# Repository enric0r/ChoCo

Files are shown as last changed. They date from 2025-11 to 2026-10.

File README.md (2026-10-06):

# ChoCo

**A USB MIDI chord controller built around a Raspberry Pi Pico.**

Choose a scale, hold a degree key, and move the joystick to change the chord. ChoCo sends MIDI notes to a software instrument, DAW, or compatible MIDI host; the connected instrument produces the sound. The OLED shows the current chord and playing modes.

[Website](https://enric0r.github.io/choco.github.io/) · [English handbook](https://enric0r.github.io/choco.github.io/docs/) · [Guida in italiano](https://enric0r.github.io/choco.github.io/it/docs/) · [Releases](https://github.com/enric0r/ChoCo/releases)

<p align="center">
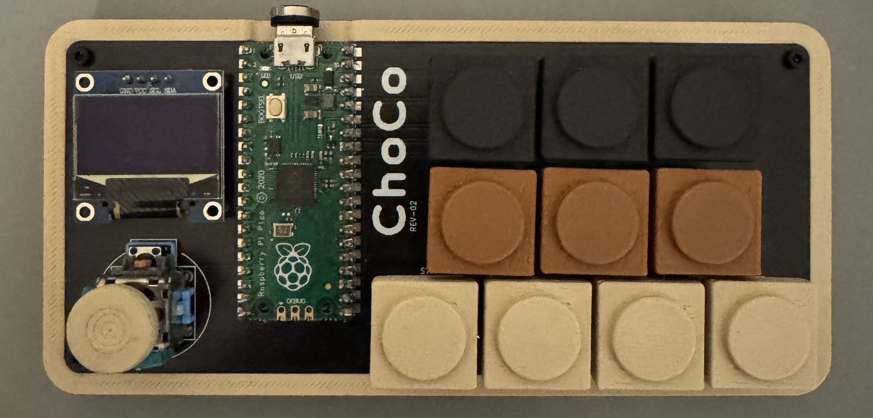
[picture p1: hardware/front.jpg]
Assembled ChoCo prototype: OLED, Raspberry Pi Pico, joystick and ten keys
  
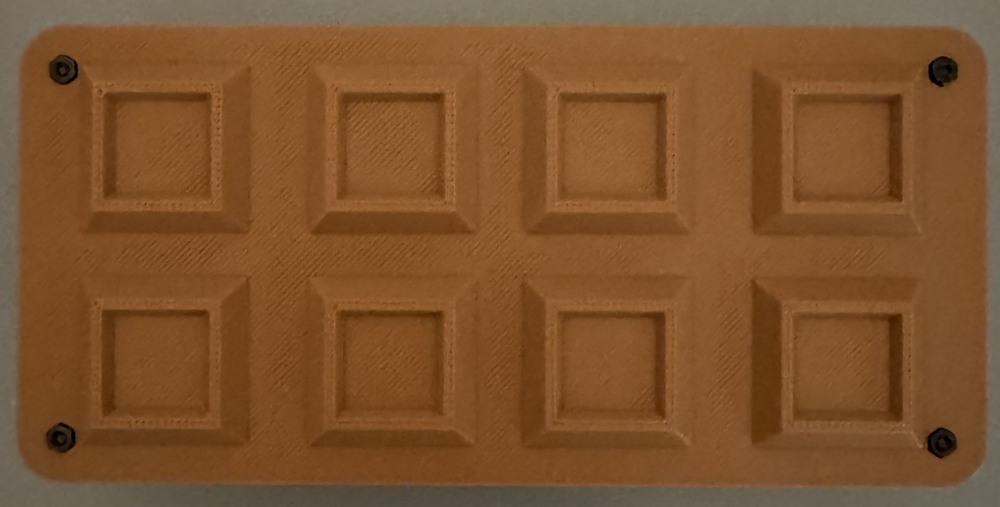
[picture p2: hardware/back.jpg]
Back of the ChoCo prototype, shaped like a chocolate bar
  
</p>

## What you can play

- **Chords in a scale.** Seven degree keys select diatonic chords. Change the root note and choose from nine scales.
- **Chord variations.** Move the joystick for suspensions, sevenths, extensions and other variations. Return it to the center for the base triad.
- **Different ways to play.** Use latch to sustain a chord, add a bass note, stagger notes with strum, or switch to single notes.
- **Inversions and voicing.** Store an inversion for each degree or enable smart voicing.
- **Feedback on the device.** The 128×64 OLED shows key, scale, chord, mode badges and harmonic suggestions.

ChoCo sends class-compliant USB MIDI through TinyUSB. This repository contains the firmware, KiCad hardware files and [STL files for the case](hardware/case/).

## Play your first chord

For an assembled controller:

1. Install the firmware if needed. Download a UF2 from [Releases](https://github.com/enric0r/ChoCo/releases), when available, or [build it below](#build-and-flash).
2. Connect ChoCo with a USB **data** cable.
3. Select its USB MIDI input in your DAW or MIDI host and load an instrument.
4. Hold key `0` to play the first degree of the selected scale.
5. Move the joystick while holding the key, then return it to the center to hear the base chord again.

Start with the [English setup guide](https://enric0r.github.io/choco.github.io/docs/#get-started) or [guida italiana](https://enric0r.github.io/choco.github.io/it/docs/#get-started) for the full walkthrough.

## Controls at a glance

The two upper rows sit halfway between the four white keys. Labels below follow the firmware:

```text
  A   B   C
  1   3   5
0   2   4   6
```

| Control | Action |
| --- | --- |
| `0–6` | Play one of the seven scale degrees |
| `A` | Raise the root by one semitone |
| `B` | Select the next scale |
| `C` | Hold as a modifier for shortcuts |
| Joystick tilt, with a degree held | Change the chord variation |
| `C` + `0–6` | Cycle the inversion for that degree |
| `C` + `A` | Toggle chord latch when A is released; cancelled if the joystick button is used for strum |
| Joystick short press, without `C` | Stop the chord and cancel pending strum notes, keeping the selected modes |
| Joystick long press, without `C` | Toggle single-note mode |

The [illustrated control map](https://enric0r.github.io/choco.github.io/docs/#controls) covers bass, strum, octave changes and the other shortcuts. See [chord variations](https://enric0r.github.io/choco.github.io/docs/#shape-a-chord) for the three joystick maps and [modes and display](https://enric0r.github.io/choco.github.io/docs/#modes-and-display) for the OLED guide.

## Build and flash

Install PlatformIO, then open this repository in a terminal or in VS Code with the PlatformIO extension. The firmware uses the Arduino RP2040 core and the `pico` environment.

```powershell
pio run
```

The UF2 file is written to `.pio/build/pico/firmware.uf2`. To install it:

1. Disconnect the Pico.
2. Hold **BOOTSEL** while connecting it over USB.
3. Copy the UF2 to the **RPI-RP2** drive. The board restarts automatically.

You can also upload through PlatformIO:

```powershell
pio run -t upload
```

`platformio.ini` sets `upload_port = COM5` for local development. Override it locally if your board uses another port. Keep the TinyUSB and network-disable build flags: they are required for this USB MIDI setup.

Serial logging is disabled by default. For diagnostics, set `CHOCO_LOG_LEVEL` in [Config.h](lib/Config/Config.h), rebuild, and run `pio device monitor`. See [DEBUGGING.md](DEBUGGING.md) for the diagnostic steps.

## Hardware and configuration

The prototype uses a Raspberry Pi Pico, ten keys wired as a 3×4 matrix, an analog joystick with a push switch, and an SSD1306-compatible 128×64 I²C OLED.

| Connection | Default pins |
| --- | --- |
| Keypad rows | GP2, GP1, GP0 |
| Keypad columns | GP3, GP4, GP5, GP6 |
| Joystick X / Y | A0 / A1 |
| Joystick switch | GP13 |
| OLED SDA / SCL | GP14 / GP15, on `Wire1` |

The [hardware directory](hardware/) contains the [schematic](hardware/ChoCo.kicad_sch), [PCB layout](hardware/ChoCo.kicad_pcb), [KiCad project](hardware/ChoCo.kicad_pro) and [REV-02 archive](hardware/ChoCo_REV-02.zip).

### 3D-printed case

The [case files and printing notes](hardware/case/) include three separate STL models exported from the Fusion 360 design:

- [Top frame](hardware/case/ChoCo-top.stl)
- [Chocolate-bar bottom](hardware/case/ChoCo-bar-bottom.stl)
- [Joystick cap](hardware/case/ChoCo-thumbstick.stl)

Import the files in millimeters at 100% scale. Each file contains one part; no slicer profile is included yet.

### Prototype bill of materials

For one ChoCo, the project files describe the parts below. This is a record of
the prototype design; exact purchased models and suppliers are still being
confirmed. See the [detailed BOM and assembly notes](hardware/BOM.md).

| Qty | Part | Project detail |
| --- | --- | --- |
| 1 | ChoCo PCB | Prototype marked REV-02 |
| 1 | Raspberry Pi Pico | RP2040 module, `A1` |
| 1 | 128×64 I²C OLED | SSD1306-compatible firmware; `J1` |
| 1 | Two-axis analog joystick with push switch | PS4-style footprint; exact model to confirm |
| 10 | Mechanical key switches | MX-style 1u PCB footprints; `S1–S10` |
| 10 | Matrix diodes | Axial DO-35 footprints; `D1–D10`; symbol describes the 1N4148 family |
| 10 | Keycaps | Visible in the prototype; exact model to confirm |
| 1 | Enclosure / base assembly | Visible in the prototype; fabrication details to confirm |
| 1 | USB data cable | Match the connector on the installed Pico |

Headers, sockets and mounting hardware depend on the actual assembly; they are
listed separately in the detailed BOM so they are not mistaken for additional
schematic components.

Pin assignments, joystick orientation and thresholds, display timings, logging and mode defaults live in [lib/Config/Config.h](lib/Config/Config.h). The [hardware guide](https://enric0r.github.io/choco.github.io/docs/#hardware) and [configuration reference](https://enric0r.github.io/choco.github.io/docs/#configuration) explain these settings.

## Developing the firmware

| Path | Purpose |
| --- | --- |
| [src/main.cpp](src/main.cpp) | Setup and main loop |
| [lib/Controls](lib/Controls/) | Keypad and joystick input |
| [lib/ChordEngine](lib/ChordEngine/) | Chords, inversions, voicing and history |
| [lib/Display](lib/Display/) | OLED rendering and status |
| [lib/MIDI](lib/MIDI/) | USB MIDI transport |
| [lib/Config](lib/Config/) | Shared configuration |
| [test/logic](test/logic/) | Host-side logic tests |

Read [CONTRIBUTING.md](CONTRIBUTING.md) before changing the firmware. Keep the main loop responsive and put hardware settings in `Config.h`.

<details>
<summary>OLED and input implementation notes</summary>

### OLED layout

The header shows the selected key/scale and active degree (`D1..D7`), or `EDIT`
while C is held. The chord is centered at the largest size that fits. The arrow
tracks joystick direction with the horizontal mirror removed; the existing
vertical mapping is preserved for the mounted device.

Active modes appear as a compact text line: `VOI` (smart voicing), `BAS` (bass),
`NOTE` (single note), `STR` (strum), `LAT` (latch). The footer normally shows
`NEXT` suggestions. Temporary confirmations replace only the footer so the
chord stays readable. Long text is fitted or explicitly truncated.

Startup uses a static CHOCO wordmark. The screensaver moves the same wordmark
with the selected key/scale on a separate line; it does not blink or invert.

### Responsiveness and feedback

- Each key and the joystick button use a 10 ms stable-edge debounce, including releases. A newly pressed degree takes over from a held degree; releasing it stops playback unless latch is enabled. Previously held degrees do not retrigger automatically. Exactly simultaneous presses select the lowest degree.
- Strum note-ons are scheduled without blocking input, and pending notes are cancelled on release or chord replacement. Smart voicing preserves only notes that have actually started.
- OLED updates remain limited to 100 ms, skip unchanged frames, and wait for pending strum notes. The first key press wakes the screen and performs its action. Sounding chords keep the screen awake.
- Joystick feedback and new chord attacks share the same hysteresis state, so a variation remains selected until the stick crosses the release threshold. Degree release is processed before joystick changes to prevent a brief extra chord on release.
- Chord names use the lowest note of the resulting voicing for slash notation, including the optional bass pedal. Bass toggles apply immediately; other voicing settings apply when the next chord is generated. The top bar shows the selected key/scale, while the main name describes the active chord.
- Display degrees `1..7` correspond to physical keys `0..6`. `NEXT` contains harmonic suggestions, not a prediction or a correctness score.
- Chord names, history and status messages use fixed buffers. Release builds keep serial output disabled; `C+B` reports this on screen unless INFO logging is enabled.

These are software guarantees covered where possible by host tests. End-to-end latency, matrix ghosting with multiple keys, OLED appearance and USB behaviour still require testing on the physical board and MIDI host.

</details>

### Testing

CI runs six host test programs and builds the firmware with `pio run`. Host tests need a native C++17 compiler; `pio test` is not configured.

<details>
<summary>Run the host logic tests with PowerShell</summary>

```powershell
New-Item -ItemType Directory -Force .test | Out-Null

g++ -std=c++17 -Wall -Wextra -pedantic -Ilib/ChordEngine test/logic/test_chord_logic.cpp -o .test/choco_logic_tests.exe
.test/choco_logic_tests.exe

g++ -std=c++17 -Wall -Wextra -pedantic -Ilib/Controls test/logic/test_joystick_direction.cpp -o .test/choco_joystick_tests.exe
.test/choco_joystick_tests.exe
```

</details>

USB delivery, joystick behavior and the OLED also need checks on a real controller and MIDI host. Follow the hardware checks in [DEBUGGING.md](DEBUGGING.md).

Run the complete suite on Linux, macOS or WSL with a native C++ compiler:

```bash
bash test/run_host_tests.sh
```

On Windows with Ubuntu installed in WSL: `wsl -d Ubuntu -- bash test/run_host_tests.sh`.
The suite covers degree bounds, scale wrapping, inversions, joystick classification, contact bounce, timer rollover, cancellable strum, overlapping keys, latch/strum shortcuts, bass ownership and chord labels. The integration test runs the actual main loop, controls and chord engine with simulated GPIO, time and MIDI. It does not emulate USB or OLED hardware. A cross-compiler such as `arm-none-eabi-g++` cannot run these host tests.

## Help and documentation

For missing MIDI input, a blank OLED or unexpected controls, start with the [troubleshooting guide](https://enric0r.github.io/choco.github.io/docs/#troubleshooting). For a reproducible problem, [open an issue](https://github.com/enric0r/ChoCo/issues).

The handbook is available in [English](https://enric0r.github.io/choco.github.io/docs/) and [Italian](https://enric0r.github.io/choco.github.io/it/docs/), with control diagrams and OLED examples. Its source lives in [choco.github.io](https://github.com/enric0r/choco.github.io).

## License

ChoCo is distributed under the [PolyForm Noncommercial License 1.0.0](LICENSE).

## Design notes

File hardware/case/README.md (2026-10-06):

# ChoCo case

Three STL parts from the Fusion 360 design of the ChoCo prototype: an open top frame, a bottom with the chocolate-bar pattern, and a joystick cap.

Back of the assembled ChoCo prototype

## Files

Download one copy of each part. On a GitHub STL page, use **Download raw file** to save the model.

| File | Part | Bounding dimensions at millimeter scale (X × Y × Z) |
| --- | --- | --- |
| [ChoCo-top.stl](ChoCo-top.stl) | Open top frame | 148.5 × 70.5 × 7 mm |
| [ChoCo-bar-bottom.stl](ChoCo-bar-bottom.stl) | Chocolate-bar bottom | 148.5 × 70.5 × 7 mm |
| [ChoCo-thumbstick.stl](ChoCo-thumbstick.stl) | Joystick cap | 14.5 × 14.5 × 7.5 mm |

STL does not encode units. Import these files as **millimeters**, at **100% scale**, and check the dimensions above in your slicer.

Each file contains one connected mesh, exported separately from Fusion 360. The files keep their original design coordinates, so move or arrange each part on the build plate in your slicer before printing. Their coordinates do not specify the best printing orientation.

## Printing and assembly

The photos show the assembled prototype, printed on a **Bambu Lab P2S**. **PLA** is the intended material. The original prints used PLA and/or PLA+; the exact filament or mix was not recorded.

Layer height, supports and fastening details have not yet been documented, and no tested slicer profile is included.

Check the orientation in your slicer and the fit of the frame, mounting holes and joystick socket against your components. The [front photo](../front.jpg) shows the placement of the frame and joystick cap; the photo above shows the outer face of the bottom.

The mesh checks confirm closed, consistently connected surfaces; they do not verify printer tolerances or assembly fit.

## Sharing and source files

These STL files can be used for a model upload on MakerWorld or Printables. A MakerWorld print profile needs a project saved from Bambu Studio with the intended printer and print settings; the STL files themselves do not include those settings.

The editable Fusion 360 project is not included yet. Links to the MakerWorld and Printables listings will be added once those listings are published.

See the repository [LICENSE](../../LICENSE) and the [ChoCo handbook](https://enric0r.github.io/choco.github.io/docs/) for the rest of the project.

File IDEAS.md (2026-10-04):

# Practical next features

The unmodified joystick short click now provides a quick stop: it stops local
playback and cancels scheduled notes while preserving the selected modes.
It is not a MIDI-host panic command and cannot guarantee recovery from a lost
USB message or an externally held sustain pedal.

## 1. User presets

Save root, scale, octave, mode flags and per-degree inversions in a few slots.
Use an explicit save gesture/menu, a versioned record and checksum; do not write
flash on every input. Validate corrupt/older records and interrupted writes.
This needs a deliberate control/menu design before implementation.

## 2. Adjustable strum and velocity

Offer a small set of strum speeds and MIDI velocity levels, with an OLED preview.
The current note scheduler already supports variable spacing. Capture settings
when a chord starts to avoid changing an attack halfway through. Define how
these controls coexist with the existing C+joystick gestures.

## 3. Guided chord exploration

Show note names for a selected suggested degree before playing it. Label the
existing weighted suggestions as suggestions; they are not an analysis of the
audio or a guarantee of a musically correct progression. Keep the preview
independent of MIDI playback and fit it to the 128x64 display.

## 4. USB delivery diagnostics and recovery

The current transport does not check the return value of `usb_midi.write`.
Add a bounded outgoing event queue with explicit overflow handling, retry of
unsent packets, connection-state handling and a visible delivery-error state.
Define reconnect behaviour first (silent reset versus resume held notes).
Test full buffers, disconnects during strum, and note-off delivery on a real
host; the current simulated MIDI sink cannot establish those guarantees.

## 5. Joystick calibration

Add an explicitly invoked center-calibration gesture with a stability check
and bounded offsets. Avoid automatic startup calibration while the stick might
be held. Test noisy/resting/off-center input and show success or rejection.

These items are proposals; only the quick-stop gesture is implemented here.

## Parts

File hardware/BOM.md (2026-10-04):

# ChoCo prototype BOM

This records the hardware described by the repository and visible in the prototype
photos, for **one controller**. It is the starting point for documenting the
builder's actual parts. Exact purchase links, manufacturers and variants remain
to be confirmed; a library label is not proof of the part purchased.

## Electronic parts

| Qty | Part | Reference | Evidence / assembly detail |
| --- | --- | --- | --- |
| 1 | Raspberry Pi Pico, RP2040 | A1 | Schematic value `RaspberryPi_Pico`; PCB footprint `ScottoKeebs_MCU:Raspberry_Pi_Pico`; module visible in the front photo. The symbol description also mentions Pico 2, but this does not establish firmware support for Pico 2. |
| 1 | 128×64 I²C OLED module | J1 | Schematic value `OLED_128x64`; footprint `ScottoKeebs_Components:OLED_128x64`. Firmware targets SSD1306 at `0x3C`. The connector reference represents the display module, not a second display. Exact module size and supplier are not recorded. |
| 1 | Two-axis analog joystick with push switch | ALPS_3318_DS4_Joystick1 (schematic) | Footprint `PS4_Joystick:PS4_joystick`. The PCB uses `REF**` and value `XDCR_COM-09032`; these inconsistent labels are not treated as a confirmed manufacturer part number. Confirm the installed joystick before using a purchase link. |
| 10 | Mechanical key switches | S1–S10 | `Scotto_MX:MX_PCB_1.00u` footprints. Switch brand, variant and operating force are not recorded. |
| 10 | Matrix diodes, axial DO-35 | D1–D10 | Value `Diode`, footprint `Scotto:Diode_DO-35`. The symbol description mentions 1N4148 / 1N4148W, but the PCB footprint is axial DO-35, not the SOD-123 package also mentioned by that generic description. Exact installed diode part number is unconfirmed. |

The schematic contains **23 physical electronic items in five groups**. It has no
populated manufacturer/MPN fields. Counts and footprints above were extracted
from the schematic and compared with the PCB; this is an inventory consistency
check, not an electrical or manufacturer-datasheet validation.

## Board and assembly items

| Qty | Item | Evidence / what remains to record |
| --- | --- | --- |
| 1 | ChoCo PCB | Front photo shows REV-02; source PCB and a REV-02 archive are included. Check the actual revision before fabrication. |
| 10 | Keycaps | Front photo shows 3 dark, 3 brown and 4 light caps. Material, dimensions and purchase or fabrication source are unconfirmed. |
| 1 assembly | Enclosure / base | Visible in front/back photos. Material, fabrication files and method are not established by these KiCad files. |
| 4 visible positions | Mounting hardware | PCB has H1–H4, `MountingHole_2.2mm_M2`; fasteners are visible in the photos. Actual screw length, nuts and spacers need confirmation. Hole footprints are not four extra electronic components. |
| As fitted | Headers / sockets | Pico and OLED connection method and separate header quantities need confirmation; do not double-count headers already supplied with a module. |
| 1 | USB data cable | Required for power and USB MIDI; choose the connector matching the installed module. |

## Details to add from the actual build

- Purchase links or manufacturer/model for the Pico, OLED, joystick and switches.
- Installed diode model and manufacturer, if known.
- Keycap and enclosure source: purchased parts or fabrication files/materials.
- Headers, sockets, screw lengths and spacers actually fitted.

Prices, stock and alternative parts are intentionally omitted: this page records
the prototype rather than selecting replacement parts or preparing an order.

## Sources

- [KiCad schematic](ChoCo.kicad_sch): quantities, values and intended footprints.
- [KiCad PCB](ChoCo.kicad_pcb): placed footprints and four mounting holes.
- [Front photo](front.jpg) and [back photo](back.jpg): visible assembly and REV-02 marking.
- [Firmware configuration](../lib/Config/Config.h): display and input configuration.
- [Project README](../README.md#prototype-bill-of-materials): short BOM.

When a purchased part is confirmed, update this page and the English/Italian
handbook together. Add confirmed manufacturer/MPN properties to the schematic
when maintaining the electrical BOM; do not infer them from a footprint name.

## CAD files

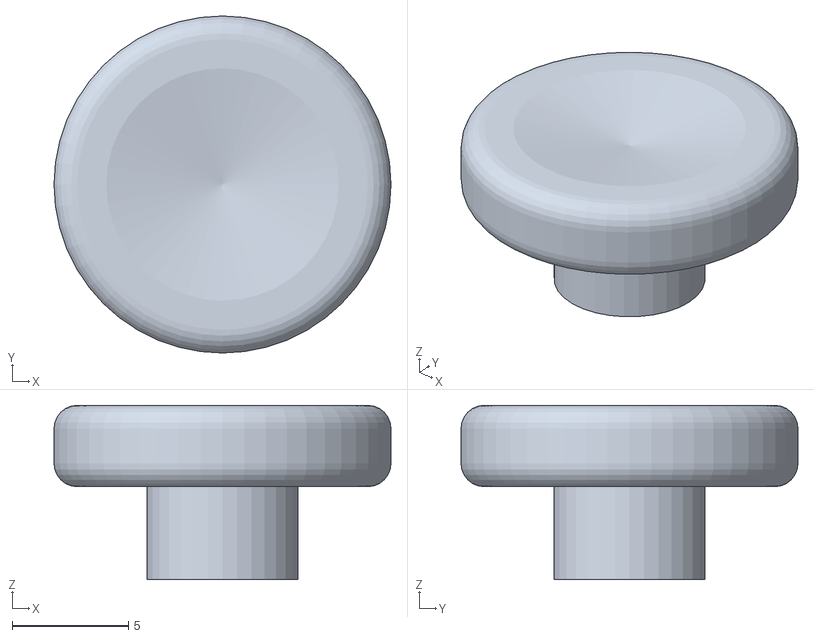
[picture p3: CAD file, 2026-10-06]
hardware/case/ChoCo-thumbstick.stl
14.5 x 14.5 x 7.50

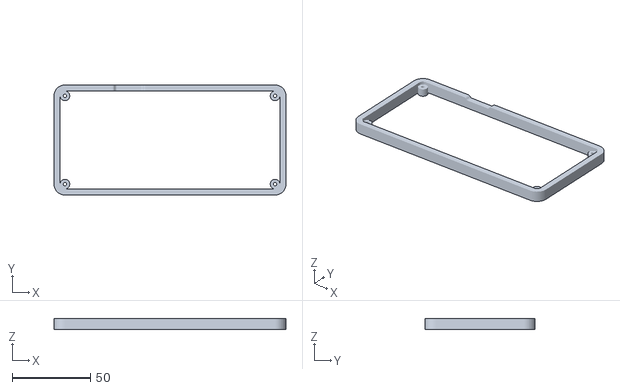
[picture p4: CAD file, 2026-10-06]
hardware/case/ChoCo-top.stl
148.5 x 70.5 x 7.00

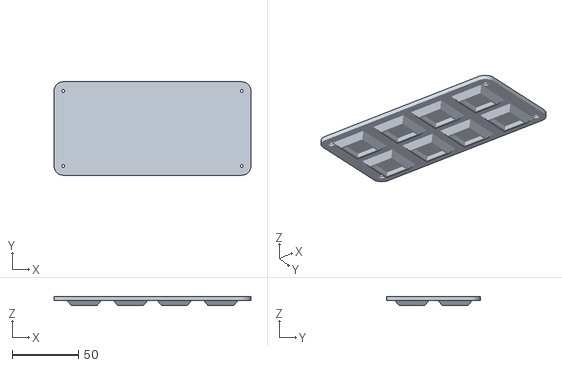
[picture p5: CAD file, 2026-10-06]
hardware/case/ChoCo-bar-bottom.stl
148.5 x 70.5 x 7.00

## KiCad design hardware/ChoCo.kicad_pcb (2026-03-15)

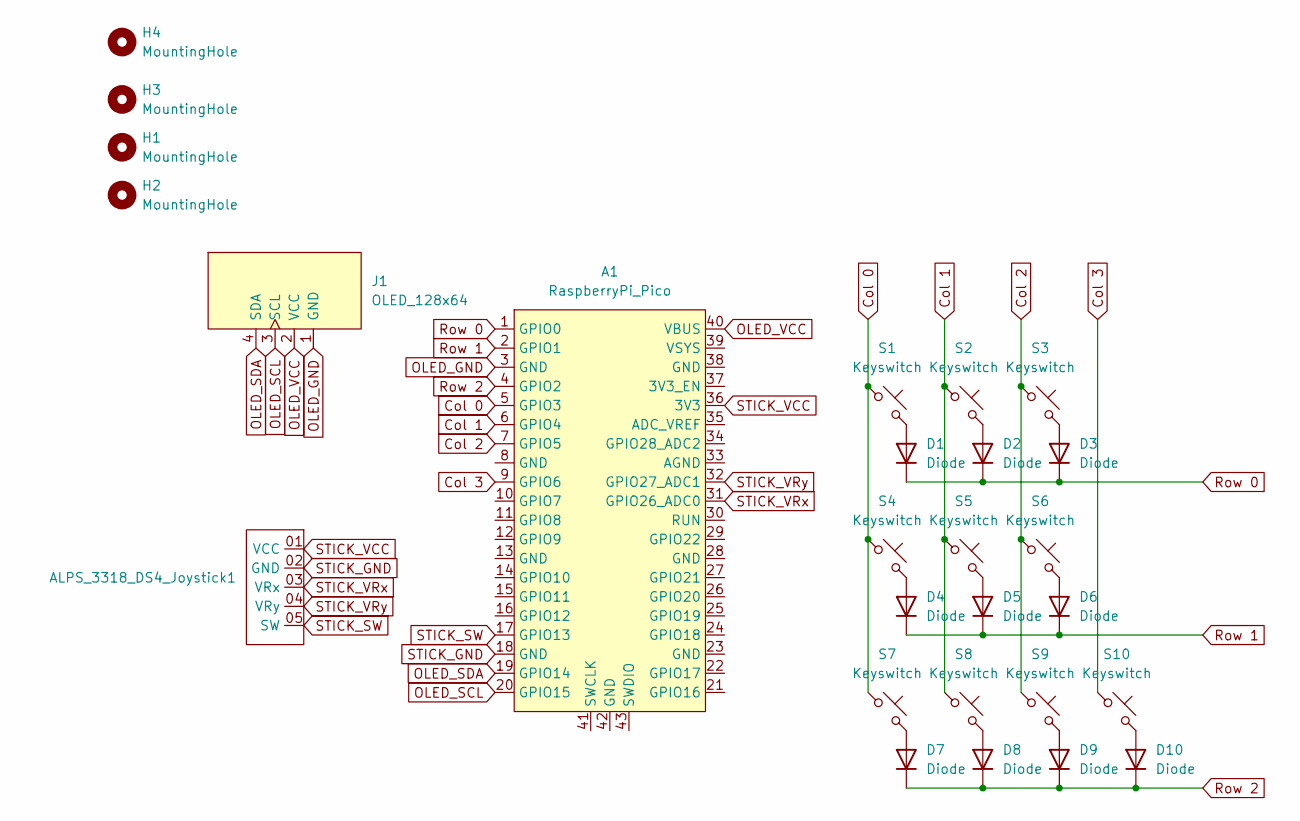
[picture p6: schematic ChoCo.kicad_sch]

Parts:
A1: RaspberryPi_Pico; Raspberry_Pi_Pico
ALPS_3318_DS4_Joystick1: PS4_joystick
D1, D2, D3, D4, D5, D6, D7, D8, D9, D10: Diode; Diode_DO-35
H1, H2, H3, H4: MountingHole; MountingHole_2.2mm_M2
J1: OLED_128x64
S1, S2, S3, S4, S5, S6, S7, S8, S9, S10: Keyswitch; MX_PCB_1.00u

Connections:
Col 0: A1.5 (GPIO3), S1.1, S4.1, S7.1
Col 1: A1.6 (GPIO4), S2.1, S5.1, S8.1
Col 2: A1.7 (GPIO5), S3.1, S6.1, S9.1
Col 3: A1.9 (GPIO6), S10.1
unnamed: D1.2 (A), S1.2
unnamed: D2.2 (A), S2.2
unnamed: D3.2 (A), S3.2
unnamed: D4.2 (A), S4.2
unnamed: D5.2 (A), S5.2
unnamed: D6.2 (A), S6.2
unnamed: D7.2 (A), S7.2
unnamed: D8.2 (A), S8.2
unnamed: D9.2 (A), S9.2
unnamed: D10.2 (A), S10.2
OLED_GND: A1.3 (GND), J1.1 (GND)
OLED_SCL: A1.20 (GPIO15), J1.3 (SCL)
OLED_SDA: A1.19 (GPIO14), J1.4 (SDA)
OLED_VCC: A1.40 (VBUS), J1.2 (VCC)
Row 0: A1.1 (GPIO0), D1.1 (K), D2.1 (K), D3.1 (K)
Row 1: A1.2 (GPIO1), D4.1 (K), D5.1 (K), D6.1 (K)
Row 2: A1.4 (GPIO2), D7.1 (K), D8.1 (K), D9.1 (K), D10.1 (K)
STICK_GND: A1.18 (GND), ALPS_3318_DS4_Joystick1.02 (GND)
STICK_SW: A1.17 (GPIO13), ALPS_3318_DS4_Joystick1.05 (SW)
STICK_VCC: A1.36 (3V3), ALPS_3318_DS4_Joystick1.01 (VCC)
STICK_VRx: A1.31 (GPIO26_ADC0), ALPS_3318_DS4_Joystick1.03 (VRx)
STICK_VRy: A1.32 (GPIO27_ADC1), ALPS_3318_DS4_Joystick1.04 (VRy)

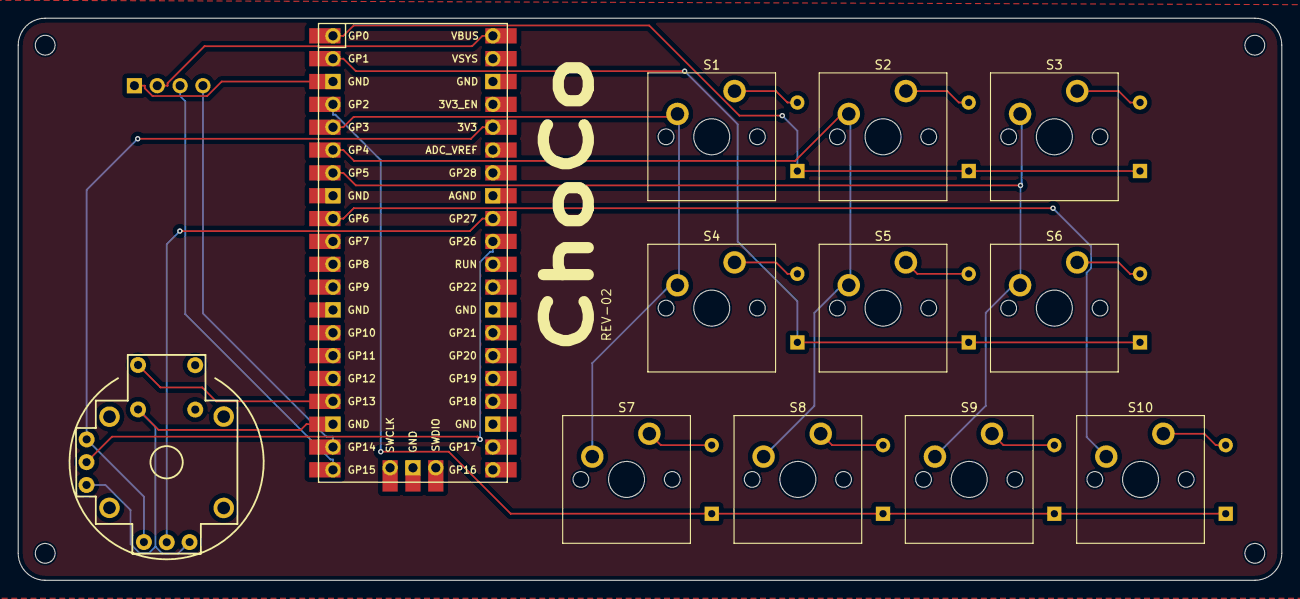
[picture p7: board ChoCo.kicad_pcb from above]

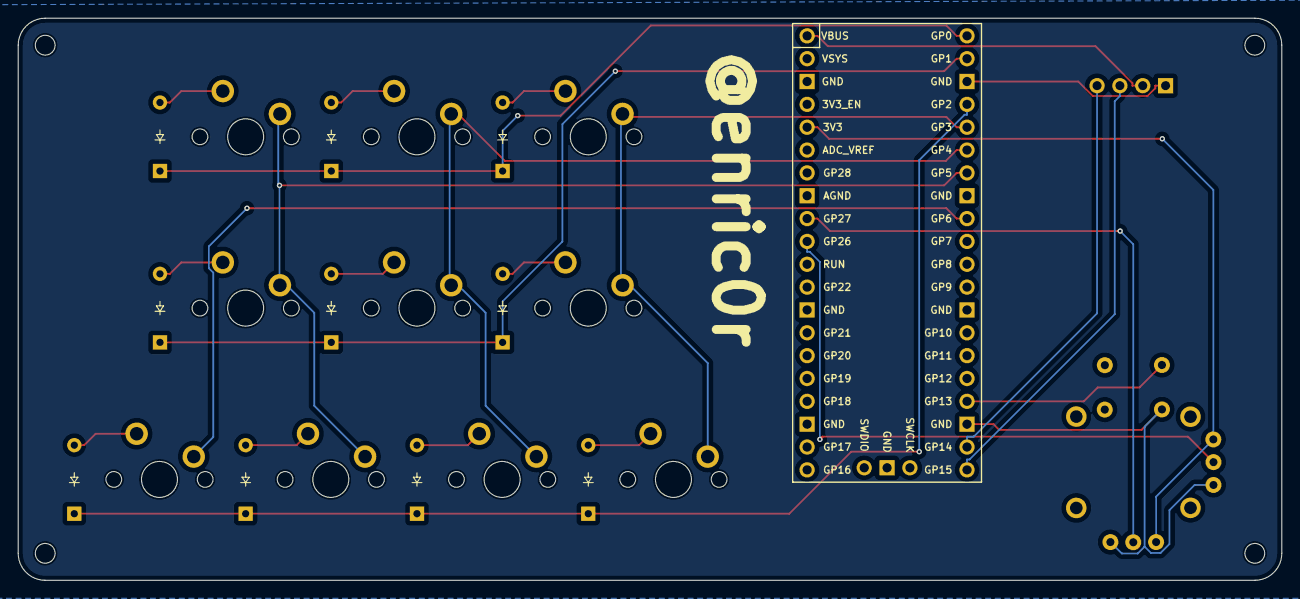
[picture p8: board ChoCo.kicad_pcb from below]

Board: 2 copper layers, 140.5 x 62.5 mm, 26 parts (10 on the bottom side), 21 nets.

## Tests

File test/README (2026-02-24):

This directory is intended for PlatformIO Test Runner and project tests.

Unit Testing is a software testing method by which individual units of
source code, sets of one or more MCU program modules together with associated
control data, usage procedures, and operating procedures, are tested to
determine whether they are fit for use. Unit testing finds problems early
in the development cycle.

More information about PlatformIO Unit Testing:
- https://docs.platformio.org/en/latest/advanced/unit-testing/index.html

Additional fast logic tests live in:
- `test/logic/test_chord_logic.cpp`
- `test/logic/test_joystick_direction.cpp`

They validate pure harmony helpers (degree bounds, scale wrap, inversion normalization)
and joystick direction classification (outer-ring octants + hysteresis) and run in CI
using a standard C++ compiler.

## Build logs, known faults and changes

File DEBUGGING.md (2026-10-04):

# ChoCo diagnostics

Release builds use `CHOCO_LOG_LEVEL_NONE` and intentionally produce no serial messages.
For diagnostics, temporarily set `CHOCO_LOG_LEVEL` in `lib/Config/Config.h` to
`CHOCO_LOG_LEVEL_INFO` or `CHOCO_LOG_LEVEL_DEBUG`, build and flash, then run
`pio device monitor`. Restore `NONE` for normal performance testing.

## Startup

INFO logging reports MIDI initialization, controls initialization, I2C devices,
display initialization and splash completion. The splash runs during setup for
approximately two seconds; it does not add delays to normal playback. If OLED
buffer allocation fails, controls and MIDI continue without display rendering.

## Input and playback

- Matrix rows are GP2, GP1, GP0; columns are GP3, GP4, GP5, GP6 with pull-ups.
  Only the row being scanned drives LOW; inactive rows are inputs.
- Key and joystick-button press/release edges must remain stable for
  `INPUT_DEBOUNCE_MS` (default 10 ms). Tune this in `Config.h`.
- DEBUG logs include joystick variations and voicing decisions. INFO includes
  chord playback and mode changes. `C+B` prints chord history only with INFO
  or higher enabled; otherwise the display reports `Serial log OFF`.
- Host regressions run with `bash test/run_host_tests.sh` or, on Windows,
  `wsl -d Ubuntu -- bash test/run_host_tests.sh`. Use a native compiler, not an ARM
  cross-compiler. The host harness simulates GPIO, time and MIDI events.

## Physical acceptance checks

Use a MIDI event monitor or a DAW and test:

1. Tap and hold every degree. Each press should start once; release should stop
   its notes, including when C or another degree remains held.
2. Hold one degree, press another, then release the newer degree. It should stop
   unless latch is enabled, without replaying the older held degree.
3. Enable strum with C+A+joystick short press. Latch must stay unchanged. Release
   a chord during its attack and check that no delayed notes appear afterwards.
4. Enable smart voicing and strum together, then switch degrees quickly. Check for
   stuck or missing notes. Toggle bass while a chord sounds and check note-offs.
5. Leave the device idle for the screensaver, then press a degree once. It should
   both wake the display and play. Hold a chord beyond 30 seconds: status stays visible.
6. Check all joystick directions, center return, OLED labels and shortened text.
   Display degree 1 means physical key 0. The horizontal arrow mirror has been removed, including diagonals; the
   vertical mapping is retained. Validate all directions against the mounted device.
7. Check USB disconnect/reconnect and long sessions with your actual MIDI host.
   Host tests cannot validate USB delivery, audible latency or analog noise.
8. Hold a joystick variation, move partway toward center and play a new degree:
   the variation should remain until the release threshold is crossed. Release
   the degree and center the stick together: no extra note-ons should appear.
9. Short-click the joystick without C while a latched chord or strum is active.
   Playback should stop; latch/strum settings should remain unchanged. The held
   degree must be released and pressed again before it plays again.

A matrix without per-key diodes can produce ambiguous ghost keys with certain
multi-key combinations. The host harness does not model that electrical effect.
If chords or modifiers behave unexpectedly, first test individual switches and
then the specific combination on the real board.

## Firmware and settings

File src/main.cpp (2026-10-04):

#include "Config.h"
#include "MIDI.h"
#include "Display.h"
#include "ChordEngine.h"
#include "Controls.h"

void setup() {
    Serial.begin(115200);
#if CHOCO_LOG_LEVEL >= CHOCO_LOG_LEVEL_INFO
    Serial.println("ChoCo MIDI Controller Starting...");
#endif
    
    //Initialize MIDI first
    setupMIDI();
#if CHOCO_LOG_LEVEL >= CHOCO_LOG_LEVEL_INFO
    Serial.println("MIDI initialized");
#endif
    
    setupControls();
#if CHOCO_LOG_LEVEL >= CHOCO_LOG_LEVEL_INFO
    Serial.println("Controls initialized");
#endif
    
    setupDisplay();
#if CHOCO_LOG_LEVEL >= CHOCO_LOG_LEVEL_INFO
    Serial.println("Display initialized");
#endif
    
    drawSplashScreen();
#if CHOCO_LOG_LEVEL >= CHOCO_LOG_LEVEL_INFO
    Serial.println("Setup complete - entering main loop");
#endif
}

void loop() {
    static char activeKey = NO_KEY;        // last key whose chord we started
    static bool latchGesturePending = false;
    static int lastXValue = JOYSTICK_CENTER_X;
    static int lastYValue = JOYSTICK_CENTER_Y;

    ControlSnapshot controls = {};
    pollControls(controls);
    setEditModeIndicator(controls.modifierCHeld);
    setInteractionState(controls.rawKey, controls.joyDirection, controls.modifierCHeld, controls.joyBtnHeld);

    // Wake and process the same input; held controls and sounding chords keep
    // the status visible even after the inactivity timeout.
    if (controls.rawKey != NO_KEY || controls.joyBtnHeld ||
        controls.joyDirection != JoystickDirection::Center || isChordActive()) {
        resetScreensaverTimer();
    }

    const bool cButtonHeld = controls.modifierCHeld;
    const char key = controls.debouncedKey;

    // Handle key presses
    if (key != NO_KEY) {
        resetScreensaverTimer();

        if (cButtonHeld && key >= '0' && key <= '6') {
            const int degree = key - '0';
            cycleInversionForDegree(degree);
            const int inv = getInversionForDegree(degree);
            char message[STATUS_TEXT_CAPACITY];
            snprintf(message, sizeof(message), "Deg %d Inv: %d", degree + 1, inv);
            showStatus(message, 800);
        } else if (cButtonHeld && key == 'A') {
            // Resolve on A release so C+A+button only changes strum.
            latchGesturePending = !controls.joyBtnHeld;
        } else if (!cButtonHeld && key >= '0' && key <= '6') {
            const int* varIntervals = nullptr;
            int varSize = 0;
            const char* varName = nullptr;
            const JoystickDirection direction = controls.joyDirection;
            const int degree = key - '0';
            const bool hasVariation = getChordVariationForDirection(direction, degree, varIntervals, varSize, varName);

            primeJoystickDirection(direction);
            if (hasVariation) {
                playChordForDegreeWithIntervals(degree, varIntervals, varSize, varName);
            } else {
                handleKeyPress(key);
            }
            activeKey = key;
        } else if (cButtonHeld && key == 'B') {
            printChordHistory();
#if CHOCO_LOG_LEVEL >= CHOCO_LOG_LEVEL_INFO
            showStatus("History sent", 600);
#else
            showStatus("Serial log OFF", 600);
#endif
        } else if (!cButtonHeld && (key == 'A' || key == 'B')) {
            handleKeyPress(key);
        }
    }

    // Reset screensaver on joystick movement (with deadzone)
    if (abs(controls.joyX - lastXValue) > JOYSTICK_ACTIVITY_DELTA || abs(controls.joyY - lastYValue) > JOYSTICK_ACTIVITY_DELTA) {
        resetScreensaverTimer();
        lastXValue = controls.joyX;
        lastYValue = controls.joyY;
    }

    if (controls.joyBtnHeld) latchGesturePending = false;
    if (latchGesturePending && !(controls.heldKeys & (1u << 7))) {
        latchGesturePending = false;
        toggleChordLatchMode();
        showStatusValue("Latch", isChordLatchMode() ? "ON" : "OFF", 800);
        if (!isChordLatchMode() && (activeKey == NO_KEY ||
            !(controls.heldKeys & (1u << (activeKey - '0'))))) {
            stopCurrentChord();
            activeKey = NO_KEY;
        }
    }
    // Release the actual sounding degree, even when A/B/C or another degree
    // remains held. The input layer already debounced this edge.
    if (activeKey != NO_KEY && !(controls.heldKeys & (1u << (activeKey - '0')))) {
        if (!isChordLatchMode()) stopCurrentChord();
        activeKey = NO_KEY;
    }
    const char gestureKey = (controls.heldKeys & (1u << 7)) ? 'A' : controls.rawKey;
    handleJoystick(controls.joyDirection, cButtonHeld, controls.joyBtnHeld, gestureKey);

    updateChordPlayback();
    // Full OLED transfers occupy the bus for milliseconds; defer them until
    // a strum has finished so note spacing and input scans stay responsive.
    if (isChordPlaybackPending()) return;
    updateScreensaver();

    static unsigned long lastUi = 0;
    if (millis() - lastUi >= UI_REFRESH_MS) {
        updateDisplay();
        lastUi = millis();
    }
}

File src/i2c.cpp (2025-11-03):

#include <Arduino.h>
#include "Wire.h"
#include <Adafruit_SSD1306.h>

#define I2C_SDA_PIN 14
#define I2C_SCL_PIN 15
#define SCREEN_ADDRESS 0x3C
#define OLED_RESET    -1
#define SCREEN_WIDTH 128
#define SCREEN_HEIGHT 64

Adafruit_SSD1306 testDisplay(SCREEN_WIDTH, SCREEN_HEIGHT, &Wire1, OLED_RESET);

void setup(){
  Serial.begin(115200);
    // Initialize a quick, local SSD1306 test display on Wire1 (GP14=SDA, GP15=SCL)
    // Note: your display is powered from VBUS (5V). Ensure the display breakout
    // has a proper regulator and that I2C pull-ups are to 3.3V or the module
    // is 5V-tolerant on the I2C pins.
    Wire1.setSDA(I2C_SDA_PIN);
    Wire1.setSCL(I2C_SCL_PIN);
    Wire1.begin();
    Wire1.setClock(400000);

    // Quick I2C scan on Wire1
    Serial.println(F("\nScanning I2C (Wire1)..."));
    for (uint8_t addr = 1; addr < 127; addr++) {
        Wire1.beginTransmission(addr);
        uint8_t err = Wire1.endTransmission();
        if (err == 0) {
            Serial.print(F("I2C device found at 0x"));
            if (addr < 16) Serial.print('0');
            Serial.println(addr, HEX);
        }
    }

    Serial.print(F("Initializing test SSD1306 at 0x"));
    Serial.println(SCREEN_ADDRESS, HEX);
    if (!testDisplay.begin(SSD1306_SWITCHCAPVCC, SCREEN_ADDRESS)) {
        Serial.println(F("Test SSD1306 allocation failed"));
    } else {
        delay(50);
        testDisplay.clearDisplay();
        testDisplay.setTextSize(2);
        testDisplay.setTextColor(SSD1306_WHITE);
        testDisplay.setCursor(10, 20);
        testDisplay.println(F("ChoCo"));
        testDisplay.setTextSize(1);
        testDisplay.setCursor(10, 45);
        testDisplay.println(F("Display test"));
        testDisplay.display();
    }
}

void loop(){

}

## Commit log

2025-11-04 Refactor chord handling and display updates; add root tracking for chords, improve status message display, and remove unused I2C test code.
2025-11-04 Add scale type management; implement scale cycling and update display to show current scale name
2025-11-04 Add chord history functionality; implement storage and display of recent chords, and integrate history printing with user controls.
2025-11-07 Refactor chord playback and display logic
    - Updated `playChord` function in `ChordEngine.cpp` to improve chord name formatting, including slash notation for inversions.
    - Enhanced logging to include detailed chord information with inversion and bass note.
    - Modified joystick handling in `Controls.cpp` to streamline button press detection, including long press functionality for toggling auto-voicing.
    - Improved display updates in `Display.cpp` to show abbreviated scale names and centered chord history.
    - Added `getScaleAbbreviation` function in `Display.h` and `Display.cpp` for compact display of scale names.
2025-11-07 Invert joystick X-axis reading to accommodate upside-down mounting
    [main.cpp]
2025-11-15 Enhance joystick handling to toggle modes based on 'C' modifier state during button press
2026-02-24 feat: Enhance control handling with joystick support and chord variations
    - Introduced JoystickDirection enum for better joystick direction classification.
    - Added ControlSnapshot struct to encapsulate control states including joystick and key states.
    - Implemented pollControls function to read and update control states in a single call.
    - Updated handleJoystick function to accept additional parameters for modifier key and joystick button state.
    - Added chord variation retrieval based on joystick direction.
    - Refactored main loop to utilize new control polling and joystick handling logic.
    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
2026-03-15 Added pcb files
    [ChoCo.kicad_pcb, ChoCo.kicad_sch]
2026-10-04 Improve control responsiveness and simplify the OLED interface (#11)
    * Link published ChoCo guide from firmware README
    * Rewrite README as project overview and getting started guide
    * Improve control responsiveness and simplify OLED interface
    * Fix screensaver text overlap and remove blinking logos
    * Document prototype bill of materials
    [main.cpp, test_firmware_controls.cpp]
2026-10-06 Add printable ChoCo case STL files (#12)
    * Add separate case STL files and printing notes
    * Use separately exported Fusion case parts
    [ChoCo-bar-bottom.stl, ChoCo-thumbstick.stl, ChoCo-top.stl]
